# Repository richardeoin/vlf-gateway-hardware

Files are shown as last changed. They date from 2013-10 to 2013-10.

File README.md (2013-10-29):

EAGLE CAD Design files for the VLF Gateway Unit

## Photo

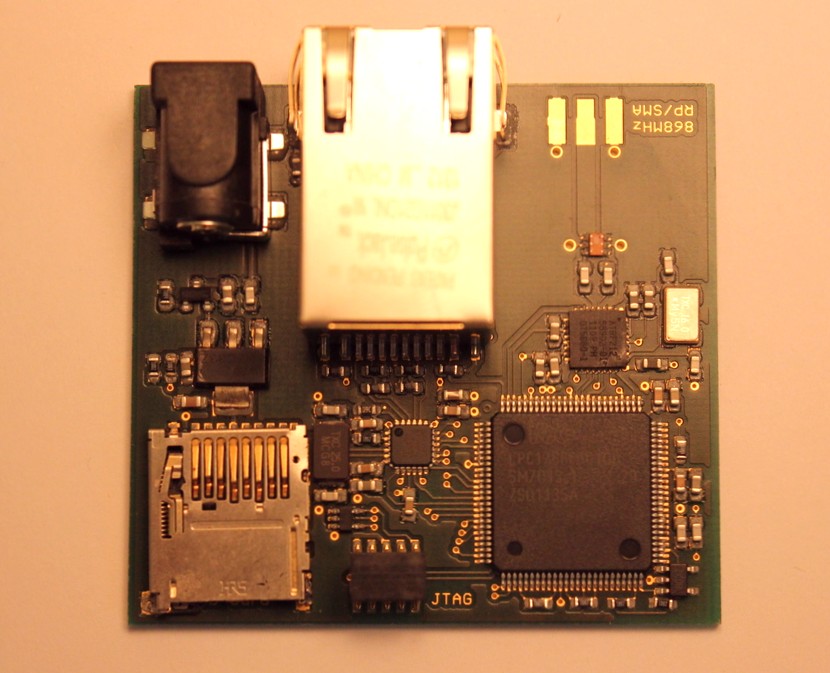
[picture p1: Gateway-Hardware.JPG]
Gateway Unit


## Design Notes

The board is based around a NXP
[LPC1766](http://www.nxp.com/documents/data_sheet/LPC1769_68_67_66_65_64_63.pdf)
ARM Cortex-M3 microcontroller. A good proportion of the board area is
given over to the ethernet PHY (an
[SMSC8720](http://www.smsc.com/media/Downloads_Public/Data_Sheets/8720a.pdf))
and connector. A small EEPROM that comes pre-programmed with a
globally unique ethernet MAC address is also included.

Data is received from the remote unit using an
[AT86RF212](http://www.atmel.com/images/doc8168.pdf) 868MHz radio and
stored on a micro SD card.

## [License](LICENSE.md)

[MIT](http://opensource.org/licenses/MIT)

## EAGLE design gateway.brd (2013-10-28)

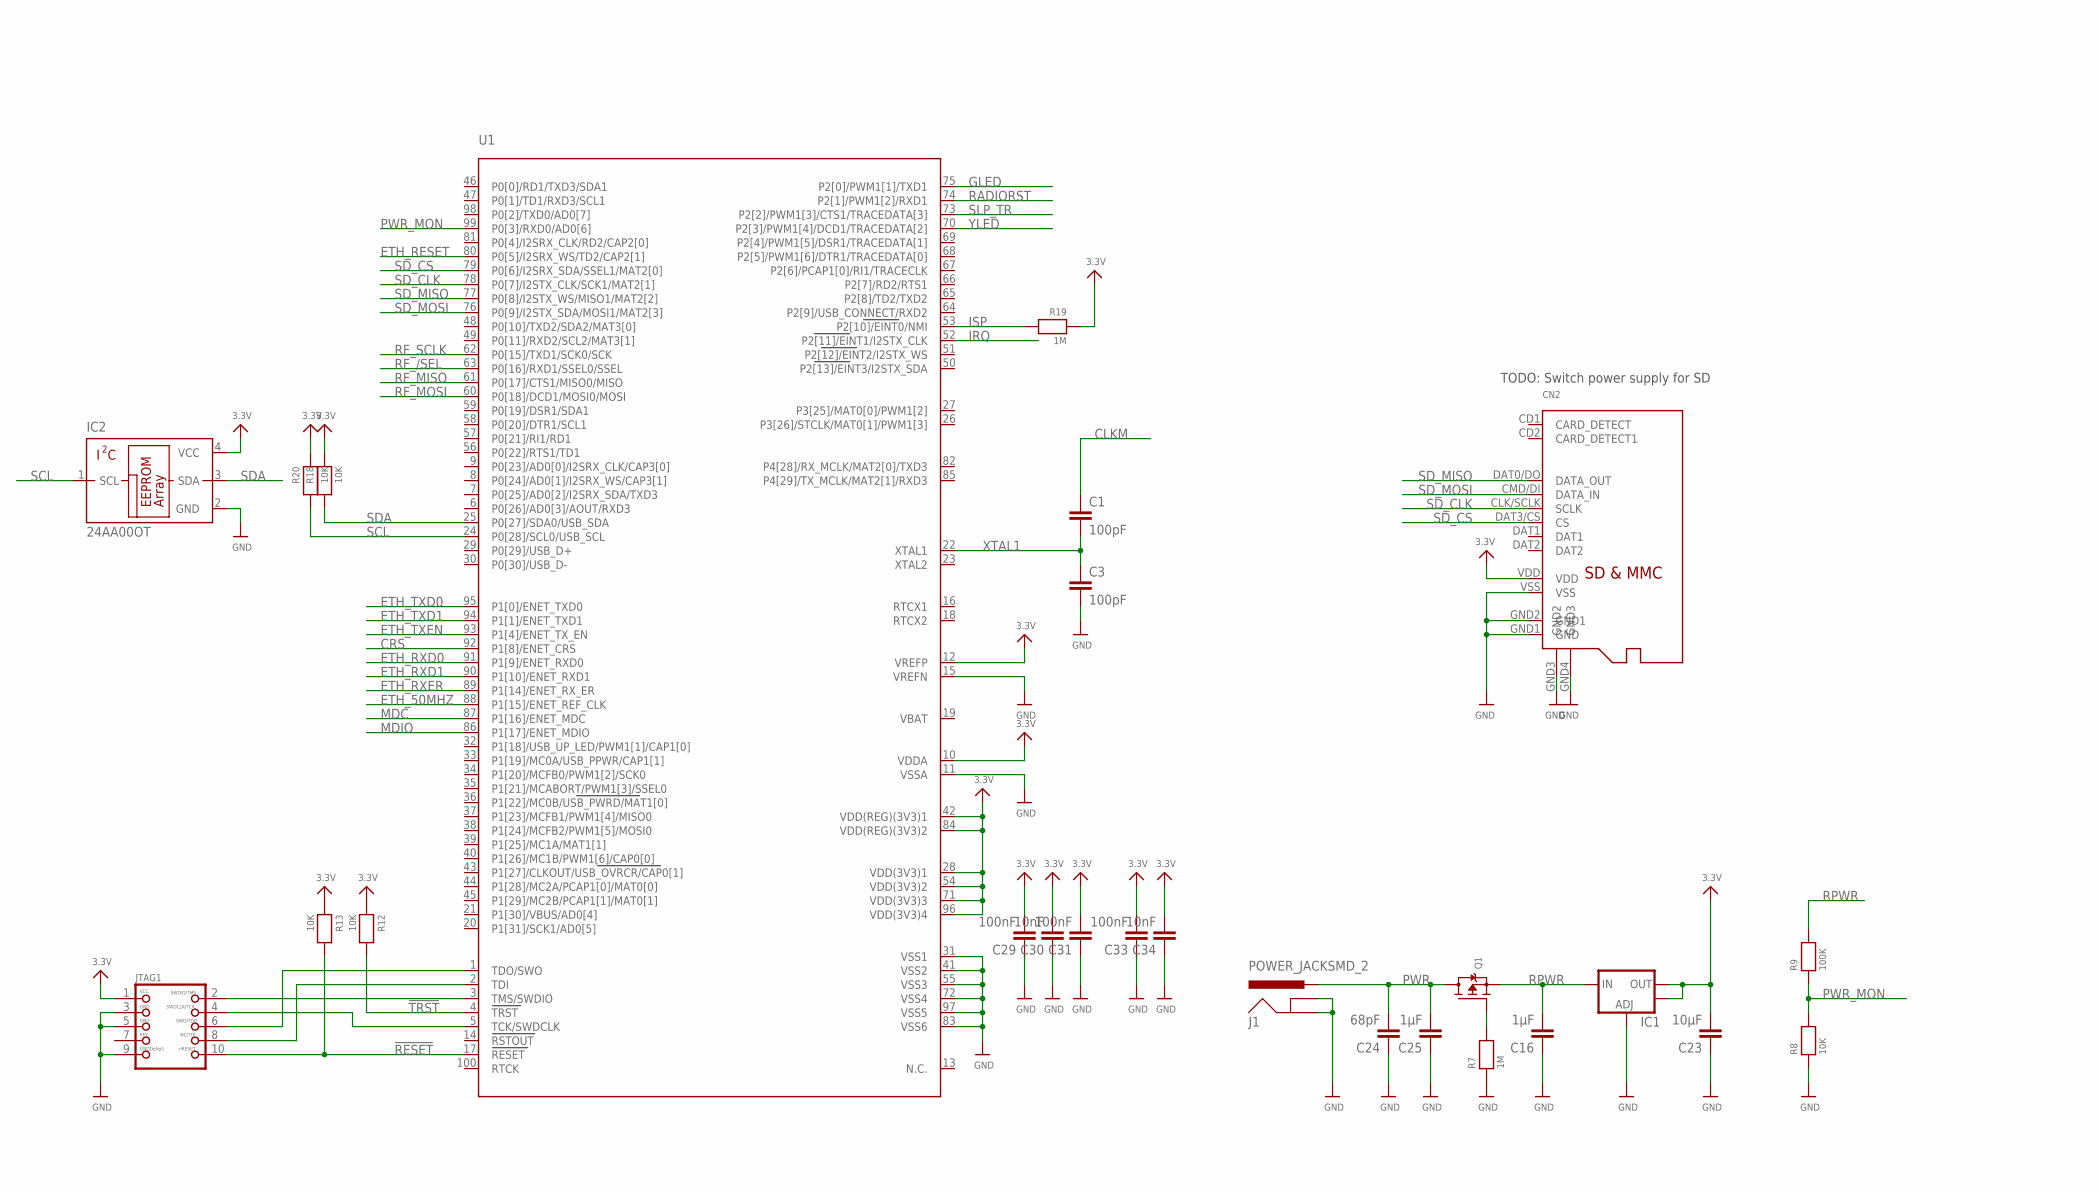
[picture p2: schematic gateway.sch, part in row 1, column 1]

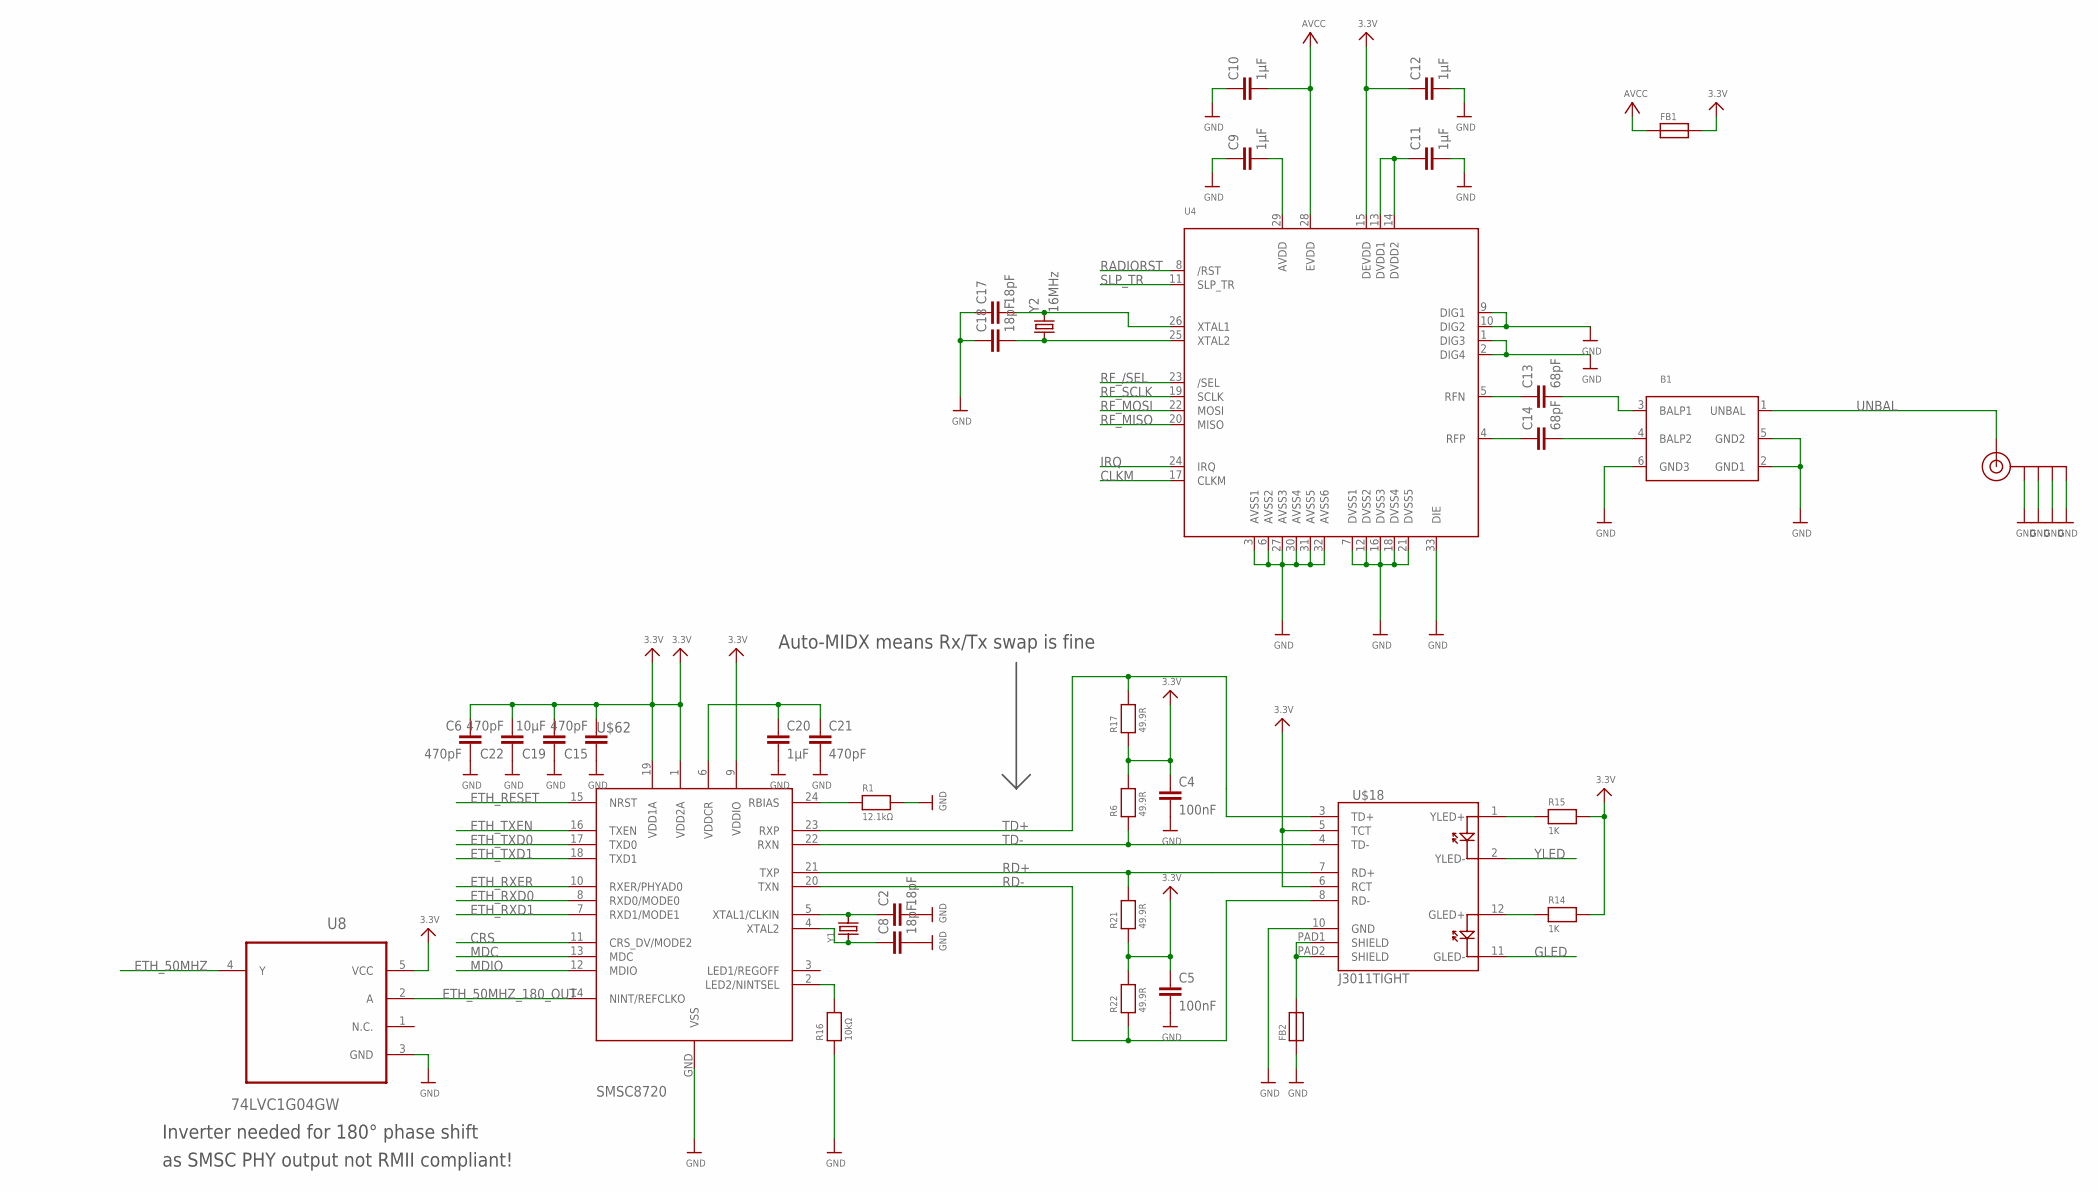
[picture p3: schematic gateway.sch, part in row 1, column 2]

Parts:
B1: BALUN+LP; BALUN0805
C1, C3: 100pF; C0603K
C2, C8, C17, C18: 18pF; C0603K
C4, C5: 100nF; C1206
C6, C15, C21, C22: 470pF; C0603K
C9, C10, C11, C12, C16, C20, C25: 1µF; C0603K
C13, C14, C24: 68pF; C0603K
C19, C23: 10µF; C0603K
C29, C31, C33: 100nF; C0603K
C30, C34: 10nF; C0603K
CN2: MICROSDDM3B; MICROSD_DM3B
FB1, FB2: FERRITE; 0603
IC1: V_REG_LM1117SOT223; SOT223
IC2: 24AA00OT; SOT23-5L
J1: POWER_JACKSMD_2; POWER_JACK_SMD_2
J$1: SMA_EDGE; SMA-EDGE
JTAG1: JTAG-CORTEXM3; 2X05_1.27MM_SMT
Q1: MOSFET-P; SOT23-R
R1: 12.1kΩ; 0603-MINI
R6, R17, R21, R22: 49.9R; 0603-MINI
R7, R19: 1M; 0603-MINI
R8, R12, R13, R18, R20: 10K; 0603-MINI
R9: 100K; 0603-MINI
R14, R15: 1K; 0603-MINI
R16: 10kΩ; 0603-MINI
U1: LPC1768; LQFP100
U4: AT86RF212; 32QN2
U8: 74LVC1G04GW; SOT65P210X110-5N
U$18: J3011TIGHT; J3011_TIGHT
U$62: SMSC8720; QFN24_SMSC8720
Y1: CRYSTALTHIN32K; CRYSTAL_4.9X1.8
Y2: 16MHz; CRYSTAL-SMD-5X3

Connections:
3.3V: C4.1, C5.1, C6.1, C12.1, C15.2, C19.2, C22.2, C23.2, C29.2, C30.2, C31.2, C33.2, C34.2, CN2.VDD, FB1.2, IC1.2 (OUT), IC1.4 (OUT), IC2.4 (VCC), JTAG1.1, R6.2, R12.1, R13.1, R14.2, R15.2, R17.1, R18.1, R19.1, R20.1, R21.1, R22.2, U1.10 (VDDA), U1.12 (VREFP), U1.28 (VDD(3V3)1), U1.42 (VDD(REG)(3V3)1), U1.54 (VDD(3V3)2), U1.71 (VDD(3V3)3), U1.84 (VDD(REG)(3V3)2), U1.96 (VDD(3V3)4), U4.15 (DEVDD), U8.5 (VCC), U$18.5 (TCT), U$18.6 (RCT), U$62.1 (VDD2A), U$62.9 (VDDIO), U$62.19 (VDD1A)
!RESET!: JTAG1.10, R13.2, U1.17 (RESET)
!TRST!: R12.2, U1.4 (TRST)
AVCC: C10.2, FB1.1, U4.28 (EVDD)
AVDD-IN: C9.2, U4.29 (AVDD)
BALP1: B1.3 (BALP1), C13.2
BALP2: B1.4 (BALP2), C14.2
CGND: FB2.2, U$18.PAD1 (SHIELD), U$18.PAD2 (SHIELD)
CLKM: C1.1, U4.17 (CLKM)
CRS: U1.92 (P1[8]/ENET_CRS), U$62.11 (CRS_DV/MODE2)
ETH_50MHZ: U1.88 (P1[15]/ENET_REF_CLK), U8.4 (Y)
ETH_50MHZ_180_OUT: U8.2 (A), U$62.14 (NINT/REFCLKO)
ETH_RESET: U1.80 (P0[5]/I2SRX_WS/TD2/CAP2[1]), U$62.15 (NRST)
ETH_RXD0: U1.91 (P1[9]/ENET_RXD0), U$62.8 (RXD0/MODE0)
ETH_RXD1: U1.90 (P1[10]/ENET_RXD1), U$62.7 (RXD1/MODE1)
ETH_RXER: U1.89 (P1[14]/ENET_RX_ER), U$62.10 (RXER/PHYAD0)
ETH_TXD0: U1.95 (P1[0]/ENET_TXD0), U$62.17 (TXD0)
ETH_TXD1: U1.94 (P1[1]/ENET_TXD1), U$62.18 (TXD1)
ETH_TXEN: U1.93 (P1[4]/ENET_TX_EN), U$62.16 (TXEN)
GLED: U1.75 (P2[0]/PWM1[1]/TXD1), U$18.11 (GLED-)
GLED+: R14.1, U$18.12 (GLED+)
GND: B1.2 (GND1), B1.5 (GND2), B1.6 (GND3), C2.2, C3.2, C4.2, C5.2, C6.2, C8.2, C9.1, C10.1, C11.2, C12.2, C15.1, C16.1, C17.1, C18.1, C19.1, C20.2, C21.2, C22.1, C23.1, C24.1, C25.1, C29.1, C30.1, C31.1, C33.1, C34.1, CN2.GND1 (GND), CN2.GND2 (GND1), CN2.GND3 (GND2), CN2.GND4 (GND3), CN2.VSS, FB2.1, IC1.1 (ADJ), IC2.2 (GND), J1.GND (GNDBREAK), J1.P$4 (GND), J$1.GND@0 (GND), J$1.GND@1 (GND), J$1.GND@2 (GND), J$1.GND@3 (GND), JTAG1.3, JTAG1.5, JTAG1.9, R1.2, R7.1, R8.1, R16.1, U1.11 (VSSA), U1.15 (VREFN), U1.31 (VSS1), U1.41 (VSS2), U1.55 (VSS3), U1.72 (VSS4), U1.83 (VSS6), U1.97 (VSS5), U4.1 (DIG3), U4.2 (DIG4), U4.3 (AVSS1), U4.6 (AVSS2), U4.7 (DVSS1), U4.9 (DIG1), U4.10 (DIG2), U4.12 (DVSS2), U4.16 (DVSS3), U4.18 (DVSS4), U4.21 (DVSS5), U4.27 (AVSS3), U4.30 (AVSS4), U4.31 (AVSS5), U4.32 (AVSS6), U4.33 (DIE), U8.3 (GND), U$18.10 (GND), U$62.GND (VSS)
IRQ: U1.52 (P2[11]/EINT1/I2STX_CLK), U4.24 (IRQ)
ISP: R19.2, U1.53 (P2[10]/EINT0/NMI)
MDC: U1.87 (P1[16]/ENET_MDC), U$62.13 (MDC)
MDIO: U1.86 (P1[17]/ENET_MDIO), U$62.12 (MDIO)
unnamed: C11.1, U4.13 (DVDD1), U4.14 (DVDD2)
unnamed: R16.2, U$62.2 (LED2/NINTSEL)
unnamed: C2.1, U$62.5 (XTAL1/CLKIN), Y1.2
unnamed: C8.1, U$62.4 (XTAL2), Y1.1
PWR: C24.2, C25.2, J1.VIN0 (PWR), Q1.3 (D)
PWR_MON: R8.2, R9.1, U1.99 (P0[3]/RXD0/AD0[6])
Q1DOWN: Q1.1 (G), R7.2
RADIORST: U1.74 (P2[1]/PWM1[2]/RXD1), U4.8 (/RST)
RBIAS: R1.1, U$62.24 (RBIAS)
RD+: R21.2, U$18.7 (RD+), U$62.21 (TXP)
RD-: R22.1, U$18.8 (RD-), U$62.20 (TXN)
RFN: C13.1, U4.5 (RFN)
RFP: C14.1, U4.4 (RFP)
RF_/SEL: U1.63 (P0[16]/RXD1/SSEL0/SSEL), U4.23 (/SEL)
RF_MISO: U1.61 (P0[17]/CTS1/MISO0/MISO), U4.20 (MISO)
RF_MOSI: U1.60 (P0[18]/DCD1/MOSI0/MOSI), U4.22 (MOSI)
RF_SCLK: U1.62 (P0[15]/TXD1/SCK0/SCK), U4.19 (SCLK)
RF_XTAL1: C17.2, U4.26 (XTAL1), Y2.3 (2)
RF_XTAL2: C18.2, U4.25 (XTAL2), Y2.1
RPWR: C16.2, IC1.3 (IN), Q1.2 (S), R9.2
SCL: IC2.1 (SCL), R20.2, U1.24 (P0[28]/SCL0/USB_SCL)
SDA: IC2.3 (SDA), R18.2, U1.25 (P0[27]/SDA0/USB_SDA)
SD_CLK: CN2.CLK/SCLK (SCLK), U1.78 (P0[7]/I2STX_CLK/SCK1/MAT2[1])
SD_CS: CN2.DAT3/CS (CS), U1.79 (P0[6]/I2SRX_SDA/SSEL1/MAT2[0])
SD_MISO: CN2.DAT0/DO (DATA_OUT), U1.77 (P0[8]/I2STX_WS/MISO1/MAT2[2])
SD_MOSI: CN2.CMD/DI (DATA_IN), U1.76 (P0[9]/I2STX_SDA/MOSI1/MAT2[3])
SLP_TR: U1.73 (P2[2]/PWM1[3]/CTS1/TRACEDATA[3]), U4.11 (SLP_TR)
TCK_SWDCLK: JTAG1.4, U1.5 (TCK/SWDCLK)
TD+: R17.2, U$18.3 (TD+), U$62.23 (RXP)
TD-: R6.1, U$18.4 (TD-), U$62.22 (RXN)
TDI: JTAG1.8, U1.2 (TDI)
TDO_SWO: JTAG1.6, U1.1 (TDO/SWO)
TMS_SWDIO: JTAG1.2, U1.3 (TMS/SWDIO)
UNBAL: B1.1 (UNBAL), J$1.SIG (SIGNAL)
VBAT: U1.19 (VBAT)
VDDCR: C20.1, C21.1, U$62.6 (VDDCR)
XTAL1: C1.2, C3.1, U1.22 (XTAL1)
YLED: U1.70 (P2[3]/PWM1[4]/DCD1/TRACEDATA[2]), U$18.2 (YLED-)
YLED+: R15.1, U$18.1 (YLED+)

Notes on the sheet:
TODO: Switch power supply for SD
Inverter needed for 180° phase shift
as SMSC PHY output not RMII compliant!
Auto-MIDX means Rx/Tx swap is fine

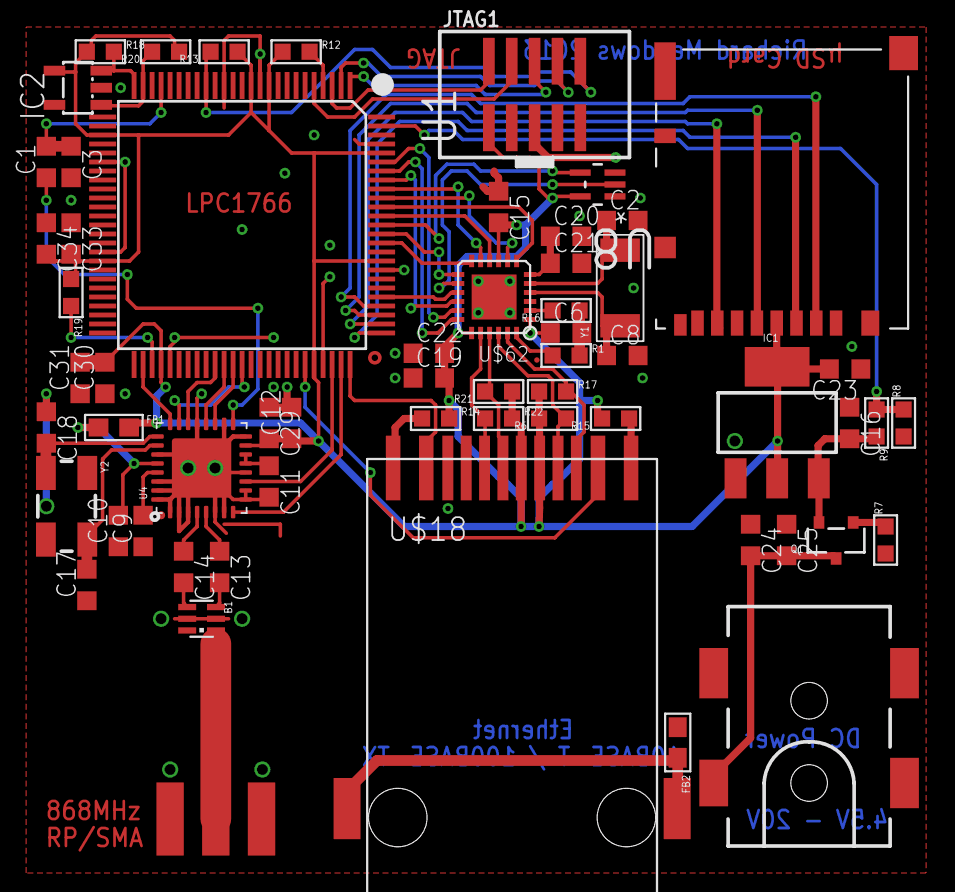
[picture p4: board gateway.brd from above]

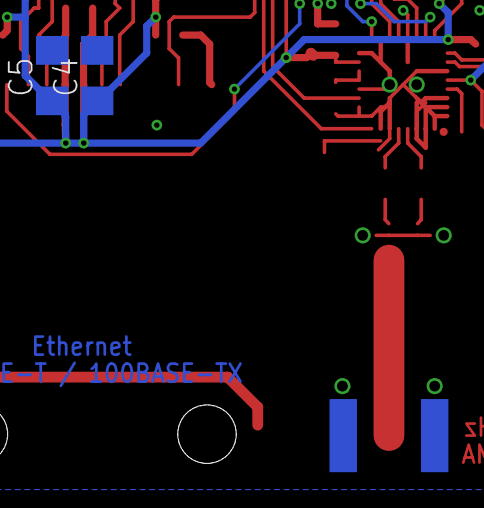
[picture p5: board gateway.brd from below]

Board: 2 copper layers, 62 parts (2 on the bottom side), 64 nets.

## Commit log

2013-10-28 Hardware Version 1
    [gateway.brd, gateway.sch]
2013-10-28 Version 2
    [gateway.brd, gateway.sch]
2013-10-28 Version 3
    [gateway.brd, gateway.sch]
2013-10-28 Version 4
    [gateway.brd, gateway.sch]
2013-10-28 Version 5
    [gateway.brd, gateway.sch]
2013-10-28 Version 6
    [gateway.brd, gateway.sch]

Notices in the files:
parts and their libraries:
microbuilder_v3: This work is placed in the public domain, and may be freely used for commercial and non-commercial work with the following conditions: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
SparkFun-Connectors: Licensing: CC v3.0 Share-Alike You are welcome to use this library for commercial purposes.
